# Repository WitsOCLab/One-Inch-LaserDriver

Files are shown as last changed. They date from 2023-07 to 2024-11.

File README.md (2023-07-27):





---

# One-Inch-LaserDriver

...

## HowTo

Use this plugin to generate what's required for manufacturing with JLCPCB: https://github.com/Bouni/kicad-jlcpcb-tools

### KiBot

[KiBot](https://github.com/INTI-CMNB/KiBot/) is used to generate all kind of documentation from a KiCAD6 project.

Whenever a file matching `pcb/*.kicad_*` changes this workflow will trigger.

The following documents are generated on every build:

```
- pcb/cad/
   - dxf/
      - AutoCAD - DXF
   - boardview - BRD
   - 3D render - STEP
- pcb/docs/
   - bom/
      - Interactive BOM - HTML
      - Octopart list - CSV
      - KiCost - XLSX (disabled)
   - schematic - PDF
- pcb/img/
   - pcb/$fab/$style/
      - PCB top - SVG
      - PCB bottom - SVG
   - render/ (disabled)
      - PCB render - PNG
   - schematic - SVG
- pcb/gerbers - ZIP
```

### REUSE

Used to ensure every file got a propper license. 

## getting started

- [ ] PCB
   - [ ] change the filenames in `pcb/*.kicad_*` matching your repository name
   - [ ] create your PCB
- [ ] run `reuse --lint`
   - [ ] make sure the licenses of `pcb/*` fits your needs
- [ ] commit and push all those changes regulary to your project

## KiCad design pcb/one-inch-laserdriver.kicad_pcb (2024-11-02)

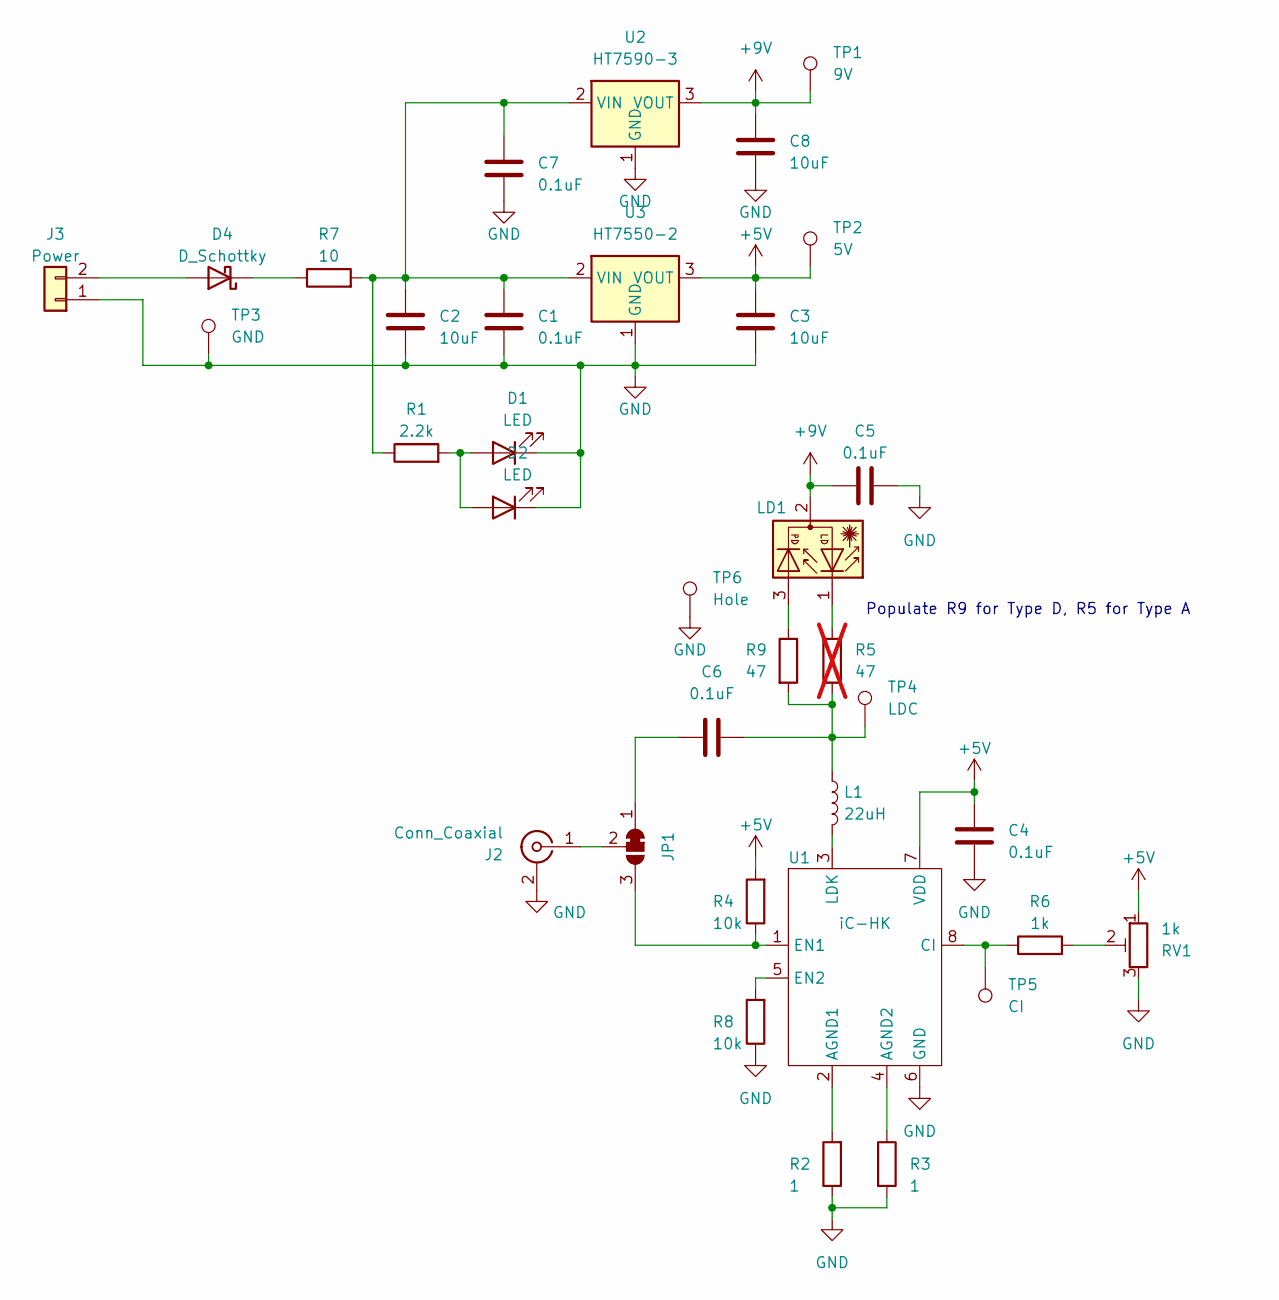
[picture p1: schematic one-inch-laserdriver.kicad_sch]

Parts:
C1, C4, C5, C6, C7: 0.1uF; C_0402_1005Metric; LCSC C307331
C2, C3, C8: 10uF; C_0603_1608Metric; LCSC C96446
D1, D2: LED; LED_0603_1608Metric; LCSC C72043
D4: D_Schottky; D_SOD-123; LCSC C8598
J2: Conn_Coaxial; MMCX_Molex_73415-1471_Vertical; LCSC C5137198
J3: Power; PinHeader_1x02_P2.54mm_Vertical
JP1: SolderJumper_3_Bridged12; SolderJumper-3_P1.3mm_Open_RoundedPad1.0x1.5mm_NumberLabels
L1: 22uH; L_Sunlord_SWPA4018S; LCSC C83443
LD1: D_Laser_Photo_NType; LaserDiode_TO18-D5.6-3
R1: 2.2k; R_0603_1608Metric; LCSC C4190
R2, R3: 1; R_0603_1608Metric; LCSC C22936
R4, R8: 10k; R_0603_1608Metric; LCSC C25804
R5: 47; R_0402_1005Metric; LCSC C25118; not fitted
R6: 1k; R_0603_1608Metric; LCSC C21190
R7: 10; R_0603_1608Metric; LCSC C22859
R9: 47; R_0402_1005Metric; LCSC C25118
RV1: 1k; Potentiometer_Bourns_3314G_Vertical; LCSC C780221
TP1: 9V; TestPoint_THTPad_D1.0mm_Drill0.5mm
TP2: 5V; TestPoint_THTPad_D1.0mm_Drill0.5mm
TP3: GND; TestPoint_THTPad_D1.0mm_Drill0.5mm
TP4: LDC; TestPoint_THTPad_D1.0mm_Drill0.5mm
TP5: CI; TestPoint_THTPad_D1.0mm_Drill0.5mm
TP6: Hole; TestPoint_THTPad_D1.0mm_Drill0.5mm
U1: iC-HK; SO-8_3.9x4.9mm_P1.27mm
U2: HT7590-3; SOT-23-5; LCSC C259667
U3: HT7550-2; SOT-23-5; LCSC C81799

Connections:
+5V: C3.1, C4.1, R4.2, RV1.1, TP2.1, U1.7 (VDD), U3.3 (VOUT)
+9V: C5.1, C8.1, LD1.2, TP1.1, U2.3 (VOUT)
GND: C1.2, C2.2, C3.2, C4.2, C5.2, C7.2, C8.2, D1.1 (K), D2.1 (K), J2.2 (Ext), J3.1, R2.1, R3.2, R8.1, RV1.3, TP3.1, TP6.1, U1.6 (GND), U2.1 (GND), U3.1 (GND)
unnamed: C6.2, L1.1, R5.1, R9.2, TP4.1
unnamed: D1.2 (A), D2.2 (A), R1.2
unnamed: D4.2 (A), J3.2
unnamed: D4.1 (K), R7.1
unnamed: J2.1 (In), JP1.2 (C)
unnamed: C6.1, JP1.1 (A)
unnamed: JP1.3 (B), R4.1, U1.1 (EN1)
unnamed: LD1.1, R5.2
unnamed: LD1.3, R9.1
unnamed: R6.2, RV1.2
unnamed: R2.2, U1.2 (AGND1)
unnamed: R3.1, U1.4 (AGND2)
unnamed: R6.1, TP5.1, U1.8 (CI)
unnamed: R8.2, U1.5 (EN2)
unnamed: L1.2, U1.3 (LDK)
unnamed: C1.1, C2.1, C7.1, R1.1, R7.2, U2.2 (VIN), U3.2 (VIN)

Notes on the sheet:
Populate R9 for Type D, R5 for Type A

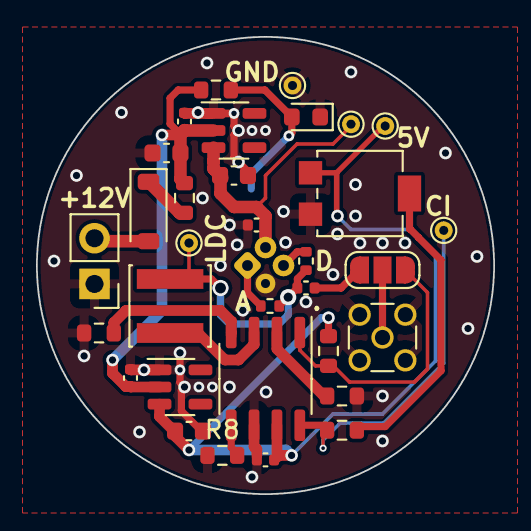
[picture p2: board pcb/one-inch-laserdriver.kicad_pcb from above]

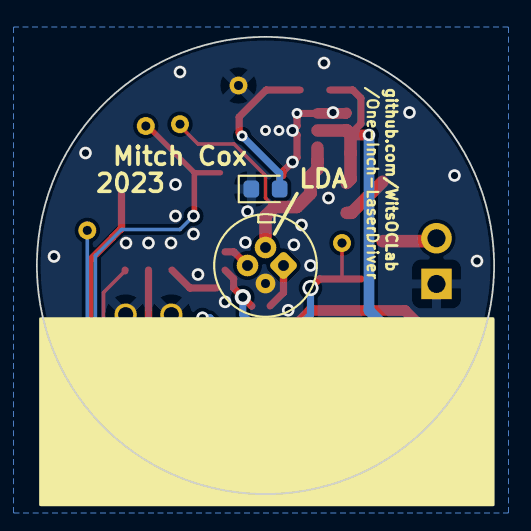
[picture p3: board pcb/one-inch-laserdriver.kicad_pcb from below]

Board: 2 copper layers, 25.4 x 25.4 mm, 35 parts (2 on the bottom side), 19 nets.

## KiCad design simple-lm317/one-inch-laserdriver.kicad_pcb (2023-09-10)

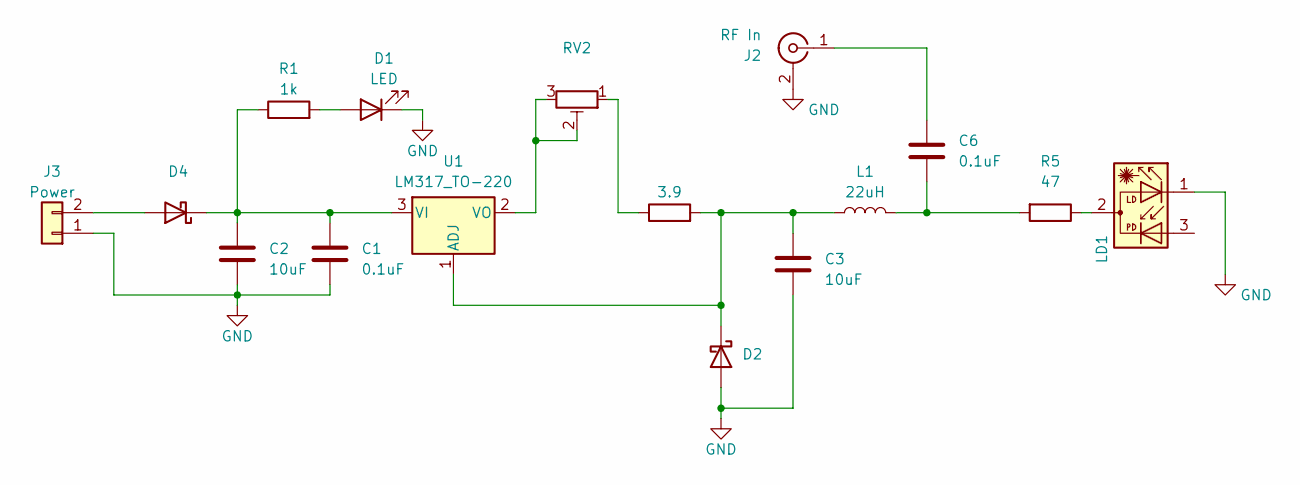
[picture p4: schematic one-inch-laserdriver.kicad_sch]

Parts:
C1, C6: 0.1uF; C_0603_1608Metric
C2, C3: 10uF; C_0603_1608Metric
D1: LED; LED_0603_1608Metric
D2, D4: D_SOD-123; LCSC C8598
J2: RF In; MMCX_Molex_73415-1471_Vertical
J3: Power; PinHeader_1x02_P2.54mm_Vertical
L1: 22uH; R_0603_1608Metric
LD1: D_Laser_Photo_NType; LaserDiode_TO18-D5.6-3
R1: 1k; R_0603_1608Metric
R5: 47; R_0603_1608Metric
R6: 3.9; R_0603_1608Metric
RV2: 200; Potentiometer_Bourns_3296W_Vertical; LCSC C780221
U1: LM317_TO-220; TO-220-3_Vertical

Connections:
GND: C1.2, C2.2, C3.2, D1.1 (K), D2.2 (A), J2.2 (Ext), J3.1, LD1.1
unnamed: C6.1, L1.2, R5.2
unnamed: D1.2 (A), R1.2
unnamed: C3.1, D2.1 (K), L1.1, R6.2, U1.1 (ADJ)
unnamed: D4.2 (A), J3.2
unnamed: C1.1, C2.1, D4.1 (K), R1.1, U1.3 (VI)
unnamed: C6.2, J2.1 (In)
unnamed: LD1.2, R5.1
unnamed 8: R6.1, RV2.1; also elsewhere on the board
unnamed 9: RV2.2, RV2.3, U1.2 (VO); also elsewhere on the board

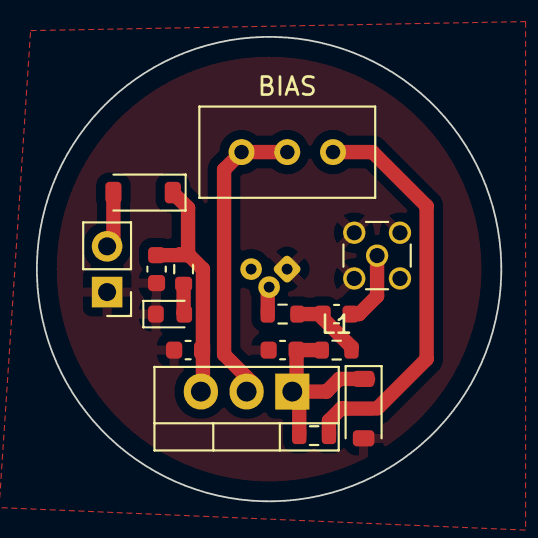
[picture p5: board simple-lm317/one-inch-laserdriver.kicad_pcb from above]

Board: 2 copper layers, 25.8 x 25.8 mm, 16 parts (1 on the bottom side), 10 nets.

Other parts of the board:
BIAS: 200; Potentiometer_Bourns_3296W_Vertical

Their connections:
unnamed 8: BIAS.1; also elsewhere on the board
unnamed 9: BIAS.2, BIAS.3; also elsewhere on the board

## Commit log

2023-07-27 almost done v1
    [one-inch-laserdriver.kicad_pcb, one-inch-laserdriver.kicad_sch]
2023-07-31 bias tee
    [one-inch-laserdriver.kicad_pcb, one-inch-laserdriver.kicad_sch]
2023-09-10 ic-HKb version done
    [one-inch-laserdriver.kicad_pcb, one-inch-laserdriver.kicad_sch]
2024-11-02 working. standard design
    [one-inch-laserdriver.kicad_pcb, one-inch-laserdriver.kicad_sch]
